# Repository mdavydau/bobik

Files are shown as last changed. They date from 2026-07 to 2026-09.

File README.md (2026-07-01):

<div align="center">

# 🤖 Tabbie  
Ever wanted a **to-do app with a Cute Face**? One that lives on your desk?

**That's Tabbie.**

[🛠️ Get started](docs/get_started.md) · [👥 Join the community](https://www.reddit.com/r/deskrobot/) · [📦 Get finished Tabbie](https://tabbie.me)

</div>

---

## 🧠 What is Tabbie?

**Tabbie is a DIY desk robot that helps you work, focus, and learn.**  
It's like a to-do app — but physical, local, and full of personality.

Tabbie lives on your desk, connects to your computer, and helps with small daily things like:
- ✅ Managing your to-do list
- ⏲️ Running Pomodoro timers
- 🔔 Setting reminders (like "drink water every 30 mins")
- 😋 Making faces, moving around, and being silly
- 🗣️ Talking to you (coming soon!)

**Think:** a mini Twitch streamer sitting on your desk, cheering you on — but also keeping you on track.

https://github.com/user-attachments/assets/2cbf9e57-a491-4764-b69d-660fd9c50714

## ✨ Made to Be Built

Tabbie is open-source and totally customizable.  
You can build it yourself with 3D-printed parts and off-the-shelf components [or just get a finished one](https://www.tabbie.me)

Powered by:
- An ESP32 microcontroller
- A local React dashboard that talks to the robot
- 3D-printed body with custom designs and colors

---

## 🚀 Get Started

Start with the step-by-step guide (WITH A **15 MINUTE VIDEO TUTORIAL**):
- 👉 See: [`docs/get_started.md`](docs/get_started.md)
- 🍎 Flash from macOS: [`docs/FLASHING_MAC.md`](docs/FLASHING_MAC.md)

That guide covers:
- Installing the Dashboard
- Flashing the ESP32 firmware
- Connecting the dashboard to your Tabbie
- First run checklist

<!-- 
**📚 Dont know anything about electronics?**  
Go here and get started → [`docs/learning/README.md`](docs/learning/README.md) — This is my mini-roadmap that I did... try learning the same _(not sure if its the best and Im kinda stupid but yea)_
-->
---

## 🗂️ Project Structure

```txt
tabbie/
├── app/                      # React control panel
│
├── firmware/                 # Code that runs on devices
│
├── hardware/                 # Physical build assets (STL files)
│
├── docs/                     # Docs (kept simple for now)
│   ├── get_started.md
│
├── CONTRIBUTING.md
└── README.md
```

---

## 🤝 Contributing

Contributions are welcome, but lets talk first!

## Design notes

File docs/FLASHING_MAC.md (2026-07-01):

# Flashing Bobik from macOS

This is the short path for rebuilding and flashing the ESP32 firmware from a
Mac.

## Fast path for Bobik

```bash
cd ~/bobik
git pull
test -f firmware/src/mqtt_config.h || cp firmware/src/mqtt_config.example.h firmware/src/mqtt_config.h
$EDITOR firmware/src/mqtt_config.h
cd firmware
pio run --target upload
```

In `firmware/src/mqtt_config.h`, keep the private broker credentials local to
your Mac. The current Bobik broker uses plain MQTT on port `1883`; do not commit
`mqtt_config.h`.

After boot, the ESP32 runs these Europe/Warsaw on-device schedules:

| Time | Face | Task |
| --- | --- | --- |
| 12:00 | `coffee` | coffee break |
| 14:30 | `status_alert` | status reminder |
| 16:00 | `sweat` | first end-of-day warning |
| 16:20 | `paused` | angrier warning |
| 16:40 | `paused` | final warning |
| 17:00 | `idle` | automatic revert from the 16:40 warning |
| 18:00-08:00 | `sleepy` | night sleepy face |
| 08:00-12:00 | `mochi_happy` | morning wake-up face |
| 00:10 | internal only | reset the stop-escalation flag for the next day |

Every real face change publishes a JSON event to MQTT topic `tabbie/notify`.
The server-side Bobik Telegram bridge subscribes to that topic and posts the
event into Bobik's Telegram channel. See
[`MQTT_BRIDGE.md`](MQTT_BRIDGE.md#4-voice-assistant-integration) for the cron
helper.

Stop the 16:00-17:00 escalation for the current day:

```bash
mosquitto_pub -h <broker-host> -p 1883 -u tabbie -P '<broker-password>' \
  -t tabbie/cmd -m '{"animation":"idle","task":"stop-escalation"}'
```

Or from the repo helper:

```bash
source .mqtt.env
tools/tabbie-pub.sh stop
```

## 1. Install tools

```bash
brew install platformio mosquitto
```

If the ESP32 does not appear as a serial port, install the CP210x driver:

```bash
brew install --cask silicon-labs-vcp-driver
```

Check the board:

```bash
pio device list
# expected: CP2102 / CP210x device, often /dev/cu.usbserial-0001
```

## 2. Create local MQTT config

```bash
cp firmware/src/mqtt_config.example.h firmware/src/mqtt_config.h
$EDITOR firmware/src/mqtt_config.h
```

Set:

```cpp
#define MQTT_HOST         "your-broker-host"
#define MQTT_PORT         1883
#define MQTT_USER         "your-user"
#define MQTT_PASS         "your-password"
```

`firmware/src/mqtt_config.h` is ignored by git. Do not commit it.

## 3. Build and upload

```bash
cd firmware
pio run
pio run --target upload --upload-port /dev/cu.usbserial-0001
```

If upload cannot connect, hold the ESP32 `BOOT` button while the upload command
is connecting.

The first clean build can take several minutes because U8g2 and the animation
headers compile from scratch. Repeat builds should be much faster.

## Preview the OLED before flashing

The app includes a local 128x64 OLED preview page. Use it to check the screen
layout and the WiFi/MQTT status overlay before uploading firmware:

```bash
cd app
PATH=/opt/homebrew/opt/node@22/bin:$PATH npm run dev -- --host 127.0.0.1
```

Open:

```text
http://127.0.0.1:8080/oled-preview.html
```

The preview can run in manual mode or poll the real device. Leave `Device URL`
as `http://tabbie.local`, or paste the direct IP address shown on the device
debug screen, for example `http://192.168.233.229`, if macOS mDNS resolution is
slow. The `PNG` button saves the current preview frame for screenshots.

When a new face header is added under `firmware/src/`, refresh the preview
assets:

```bash
python3 tools/export_oled_animations.py
```

This regenerates `app/public/animations/*.json` and `manifest.json`, and the
preview page will automatically show every exported face in the `Screen` menu.

## Mac tools for previewing and monitoring

Use these tools for different jobs:

| Tool | Best for | Install / run |
| --- | --- | --- |
| Local OLED preview | Fast face/layout checks from exported firmware assets | `cd app && PATH=/opt/homebrew/opt/node@22/bin:$PATH npm run dev -- --host 127.0.0.1` |
| Wokwi for VS Code | Full ESP32 + virtual OLED simulation without flashing hardware | Install VS Code, then install the `Wokwi Simulator` extension |
| Wokwi CLI | Terminal/CI Wokwi simulations after the VS Code setup is working | `curl -L https://wokwi.com/ci/install.sh \| sh` |
| PlatformIO monitor | Live logs from the real ESP32 over USB | `cd firmware && pio device monitor -p /dev/cu.usbserial-0001 -b 115200` |
| Arduino IDE | GUI serial monitor / serial plotter for the real ESP32 | `brew install --cask arduino-ide` |

Wokwi needs two project files in the repo root when we wire it up:
`wokwi.toml` points at the compiled firmware/ELF, and `diagram.json` describes
the ESP32 + OLED wiring. For Bobik the useful target is an ESP32 plus a 128x64
I2C SSD1306-compatible OLED. Our physical display is SH1106, but the preview
and current firmware drawing are 128x64 monochrome, so Wokwi is still useful for
screen/layout iteration before real flashing.

## 4. Configure WiFi

WiFi credentials are saved on the ESP32 in Preferences. A normal firmware upload
does not erase them.

For a new board or after reset:

1. Connect to the `Tabbie-Setup` WiFi network.
2. Open the setup page shown by the board.
3. Save the home WiFi SSID/password.
4. Let the ESP32 reboot and reconnect.

## 5. Test MQTT

Watch status:

```bash
mosquitto_sub -h your-broker-host -p 1883 -u your-user -P 'your-password' -t tabbie/status
```

Send a command:

```bash
mosquitto_pub -h your-broker-host -p 1883 -u your-user -P 'your-password' \
  -t tabbie/cmd -m '{"animation":"love","task":"mac test"}'
```

Or use the helper:

```bash
MQTT_HOST=your-broker-host MQTT_USER=your-user MQTT_PASS='your-password' \
  tools/tabbie-pub.sh love
```

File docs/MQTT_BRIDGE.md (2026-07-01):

# MQTT bridge — control Tabbie from a remote server / voice assistant

When your controller (e.g. a voice assistant) runs on a **remote server** and the
only always-on device at home is the ESP32 itself, this is the robust path: the
board **dials out** to an MQTT broker on your server and listens for commands.
No port-forwarding, no NAT holes, no always-on home box.

```
voice assistant ──publish──▶ tabbie/cmd  ┐
                                          ├─ MQTT broker (your server)
Tabbie (ESP32) ──subscribe──────────────▶┘   (board connected outbound)
Tabbie ──publish "online"──▶ tabbie/status
```

Verified working on the LAN with Mosquitto before writing this.

---

## 1. Enable the bridge in firmware

The bridge compiles **only** when `firmware/src/mqtt_config.h` exists (so the
repo still builds without it, and your broker creds stay out of git).

```bash
cd firmware/src
cp mqtt_config.example.h mqtt_config.h
$EDITOR mqtt_config.h        # set MQTT_HOST, port, MQTT_USER/MQTT_PASS
cd .. && pio run --target upload
```

`mqtt_config.h` is gitignored. Key fields:

| Define | Meaning |
|---|---|
| `MQTT_HOST` | your server's public hostname or IP |
| `MQTT_PORT` | `1883` (plain MQTT; TLS is not built in — see §5) |
| `MQTT_USER` / `MQTT_PASS` | broker credentials (comment out for anonymous) |
| `MQTT_CMD_TOPIC` | topic the board subscribes to (`tabbie/cmd`) |
| `MQTT_STATUS_TOPIC` | topic the board publishes `online` to (`tabbie/status`) |

On boot the board connects, subscribes to `MQTT_CMD_TOPIC`, retries every 5s if
the broker is down, and never blocks the display loop.

### macOS flashing notes

Install the CLI tools once:

```bash
brew install platformio mosquitto
```

Check that the ESP32 is visible:

```bash
pio device list
# or:
ls /dev/cu.*
```

Most boards appear as a CP2102/CP210x serial device such as
`/dev/cu.usbserial-0001`. If no USB serial port appears, install the Silicon
Labs driver:

```bash
brew install --cask silicon-labs-vcp-driver
```

The firmware uses `huge_app.csv` and explicit PlatformIO dependencies so clean
builds work reproducibly with the MQTT and animation assets. A first clean build
can take several minutes; repeat builds should normally finish in a few seconds.

---

## 2. Run a broker on your server (Mosquitto)

```bash
# Debian/Ubuntu
sudo apt install mosquitto mosquitto-clients

# create a user (recommended)
sudo mosquitto_passwd -c /etc/mosquitto/passwd tabbie

# /etc/mosquitto/conf.d/tabbie.conf
listener 1883 0.0.0.0
allow_anonymous false
password_file /etc/mosquitto/passwd

sudo systemctl restart mosquitto
```

Open port **1883** to the board's source (your home IP) in the server firewall.
Or run it in Docker:

```bash
docker run -d --name mosquitto -p 1883:1883 \
  -v "$PWD/mosquitto.conf:/mosquitto/config/mosquitto.conf" \
  -v "$PWD/passwd:/mosquitto/config/passwd" eclipse-mosquitto
```

---

## 3. Send commands

Commands published to `tabbie/cmd` may be **JSON** or a **bare animation name**:

```bash
# JSON
mosquitto_pub -h YOUR_SERVER -u tabbie -P secret -t tabbie/cmd \
  -m '{"animation":"paused","task":"go rest"}'

# persistent OLED DevMode diagnostics screen
mosquitto_pub -h YOUR_SERVER -u tabbie -P secret -t tabbie/cmd \
  -m '{"dev":true}'
mosquitto_pub -h YOUR_SERVER -u tabbie -P secret -t tabbie/cmd \
  -m '{"dev":false}'
mosquitto_pub -h YOUR_SERVER -u tabbie -P secret -t tabbie/cmd \
  -m '{"dev":"toggle"}'

# bare name
mosquitto_pub -h YOUR_SERVER -u tabbie -P secret -t tabbie/cmd -m love
mosquitto_pub -h YOUR_SERVER -u tabbie -P secret -t tabbie/cmd -m "dev on"
mosquitto_pub -h YOUR_SERVER -u tabbie -P secret -t tabbie/cmd -m "dev off"

# stop today's 16:00-17:00 escalation
mosquitto_pub -h YOUR_SERVER -u tabbie -P secret -t tabbie/cmd \
  -m '{"animation":"idle","task":"stop-escalation"}'
```

Or use the helper `tools/tabbie-pub.sh` (friendly words → JSON):

```bash
MQTT_HOST=YOUR_SERVER MQTT_USER=tabbie MQTT_PASS=secret \
  tools/tabbie-pub.sh angry
MQTT_HOST=YOUR_SERVER MQTT_USER=tabbie MQTT_PASS=secret \
  tools/tabbie-pub.sh dev-on
MQTT_HOST=YOUR_SERVER MQTT_USER=tabbie MQTT_PASS=secret \
  tools/tabbie-pub.sh dev-off
MQTT_HOST=YOUR_SERVER MQTT_USER=tabbie MQTT_PASS=secret \
  tools/tabbie-pub.sh debug-on
MQTT_HOST=YOUR_SERVER MQTT_USER=tabbie MQTT_PASS=secret \
  tools/tabbie-pub.sh stop
```

Animations: `idle focus break paused`(animated angry)` love pomodoro complete startup sweat sleepy coffee mochi_happy mochi_angry mochi_love upiir_big_smile status_alert`.
DevMode is the internal debug screen. It is a live feature flag toggled over
MQTT, so switching it on/off does not require reflashing. It stays on until
switched off and rotates through WiFi/MQTT, current face/task/schedule, and
system values. The helper accepts both `dev-*` and `debug-*` aliases for this
screen. Use `/api/debug` for the shorter 8-second status screen. While DevMode
is on, the firmware also writes a compact snapshot to the USB serial log every
5 seconds.

Mochi-style faces can be switched over MQTT with friendly aliases:

```bash
tools/tabbie-pub.sh mochi-happy
tools/tabbie-pub.sh mochi-angry
tools/tabbie-pub.sh mochi-love
tools/tabbie-pub.sh big-smile
tools/tabbie-pub.sh status-alert
tools/tabbie-pub.sh sleepy
```

---

## 4. Voice-assistant integration

On the server, the voice assistant should call `tools/tabbie-pub.sh`. The
script publishes to `tabbie/cmd`; Bobik receives the command over MQTT and
changes the face without reflashing.

Server setup:

```bash
cd /root/bobik
source .mqtt.env

# Smoke test: should switch the device immediately.
tools/tabbie-pub.sh status-alert "voice assistant smoke test"
```

Expected `.mqtt.env` variables:

```bash
export MQTT_HOST=localhost
export MQTT_PORT=1883
export MQTT_USER=tabbie
export MQTT_PASS='your-broker-password'
export MQTT_TOPIC=tabbie/cmd
export MQTT_NOTIFY_TOPIC=tabbie/notify
```

Intent mapping:

```
"make tabbie angry"       -> tools/tabbie-pub.sh angry
"tabbie focus mode"       -> tools/tabbie-pub.sh focus
"tabbie celebrate"        -> tools/tabbie-pub.sh complete
"tabbie mochi happy"      -> tools/tabbie-pub.sh mochi-happy
"tabbie mochi angry"      -> tools/tabbie-pub.sh mochi-angry
"tabbie mochi love"       -> tools/tabbie-pub.sh mochi-love
"tabbie big smile"        -> tools/tabbie-pub.sh big-smile
"tabbie status reminder"  -> tools/tabbie-pub.sh status-alert
"tabbie sleepy"           -> tools/tabbie-pub.sh sleepy
"tabbie dev mode on"      -> tools/tabbie-pub.sh dev-on
"tabbie dev mode off"     -> tools/tabbie-pub.sh dev-off
"bobik stop"              -> tools/tabbie-pub.sh stop
```

Watch the board come/go online:

```bash
source .mqtt.env
mosquitto_sub -h "$MQTT_HOST" -p "$MQTT_PORT" -u "$MQTT_USER" -P "$MQTT_PASS" -t tabbie/status
```

Forward face-change events to Bobik's Telegram channel by subscribing the server
bridge to `tabbie/notify`. The ESP32 publishes this topic whenever the current
face actually changes, no matter whether the change came from the on-device
schedule, HTTP dashboard, MQTT command, or an automatic return to idle.

Example event:

```json
{"event":"face-change","anim":"sleepy","animation":"sleepy","task":"sleepy time","uptime":12345,"time":"2026-07-01 19:34"}
```

Minimal server setup for Telegram forwarding:

```bash
cd /root/bobik
source .mqtt.env
source .telegram.env
tools/tabbie-notify-telegram.sh once
```

Expected `.telegram.env` variables:

```bash
export TELEGRAM_BOT_TOKEN='your-telegram-bot-token'
export TELEGRAM_CHAT_ID='your-chat-or-channel-id'
```

Create both files from the committed examples, then fill in real server values:

```bash
cp .mqtt.env.example .mqtt.env
cp .telegram.env.example .telegram.env
$EDITOR .mqtt.env .telegram.env
```

For the current Bobik flow, run the helper from cron every minute. It listens
for almost the full minute, forwards any `tabbie/notify` events, then exits so
cron can start the next window:

```cron
* * * * cd /root/bobik && . ./.mqtt.env && . ./.telegram.env && flock -n /tmp/tabbie-notify.lock tools/tabbie-notify-telegram.sh cron >> /var/log/tabbie-notify.log 2>&1
```

This creates the live loop:

```text
ESP32 schedule/face change -> tabbie/notify -> MQTT broker -> cron helper -> Telegram
Telegram/assistant "stop" -> tools/tabbie-pub.sh stop -> tabbie/cmd -> ESP32
```

Check the currently shown face from the LAN:

```bash
curl -s http://192.168.233.229/api/status
```

Direct raw MQTT payloads also work if the assistant cannot call shell scripts:

```bash
mosquitto_pub -h "$MQTT_HOST" -p "$MQTT_PORT" -u "$MQTT_USER" -P "$MQTT_PASS" \
  -t tabbie/cmd -m '{"animation":"status_alert","task":"voice assistant"}'
```

The after-hours behaviour now runs on the ESP32 itself: escalation happens at
16:00/16:20/16:40, `sleepy` holds from 18:00 until 08:00, and `mochi_happy`
wakes Bobik up from 08:00 until the noon coffee break. The legacy
`tools/tabbie_mood.sh` script is only for manual experiments.

---

## 5. Security

- The board uses **plain MQTT (1883)** — fine on a trusted network/VPN, but over
  the public internet anyone who reaches the broker can drive your Tabbie.
  **Always set a broker username/password** (§2) and restrict port 1883 by source
  IP. Avoid anonymous brokers except for LAN testing.
- TLS (port 8883) isn't compiled in to keep flash small; if you need it, add
  `WiFiClientSecure` + the broker CA and rebuild (there's now plenty of flash
  with the `huge_app` partition).

---

## 6. Local LAN test (what was used to verify this)

```bash
# on a Mac/PC on the same WiFi as Tabbie
brew install mosquitto
printf 'listener 1883 0.0.0.0\nallow_anonymous true\n' > /tmp/m.conf
mosquitto -c /tmp/m.conf -v        # note this machine's LAN IP

# set MQTT_HOST in mqtt_config.h to that LAN IP, reflash, then:
mosquitto_pub -h <lan-ip> -t tabbie/cmd -m '{"animation":"love"}'
```

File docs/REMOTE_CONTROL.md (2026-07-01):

# Controlling Tabbie remotely (incl. from a voice assistant)

Tabbie runs a small HTTP server on the ESP32. Anything that can reach the board
on the network can drive its face with a single HTTP request — no app required.
This doc covers the API, a helper CLI, how to reach the board from another
machine (e.g. a server running a voice assistant), and the security caveats.

> **About the servo / "motor":** the firmware calls `moveServoTo()` for a neck
> servo on **GPIO 13**. If no servo is attached those calls are harmless no-ops —
> the ESP32 just writes a PWM value to an unconnected pin. Faces work without any
> motor. Add a servo later and head-movement starts working with no code change.

---

## 1. HTTP API

Base URL: `http://<tabbie-host>` where `<tabbie-host>` is `tabbie.local`
(mDNS) or the board's LAN IP (e.g. `192.168.233.229`). CORS is open (`*`).

| Method | Path | Body | Purpose |
|---|---|---|---|
| `GET`  | `/api/status` | — | JSON: status, current animation, ip, ssid, rssi, uptime |
| `POST` | `/api/animation` | `{"animation":"<name>","task":"<text>","duration":<sec>}` | Set the face. `duration` only used by `focus`. |
| `POST` | `/api/servo` | (test payload) | Manually exercise the neck servo |
| `POST` | `/api/debug` | — | Show device info on screen briefly |
| `POST` | `/api/reset` | — | Clear WiFi creds and reboot into setup mode |

`GET /api/status` also includes `devMode`. Over MQTT, publish `{"dev":true}`,
`{"dev":false}`, or `{"dev":"toggle"}` to show or hide the persistent on-device
DevMode diagnostics screen. The helper supports `tools/tabbie-pub.sh dev-on`,
`dev-off`, `debug-on`, and `debug-off` aliases for the same screen.

### Expressions (`animation` values)

`idle` · `focus` · `break` · `paused` (animated **angry**) · `love` ·
`pomodoro` · `complete` · `startup` · `sweat` · `coffee` ·
`mochi_happy` · `mochi_angry` · `mochi_love` · `upiir_big_smile` ·
`status_alert`

Friendly helper aliases: `mochi-happy`, `mochi-angry`, `mochi-love`,
`big-smile`, `status-alert`.

### Examples

```bash
# status
curl -s http://tabbie.local/api/status

# angry face (the animated one), with a label
curl -s -X POST http://tabbie.local/api/animation \
  -H "Content-Type: application/json" \
  -d '{"animation":"paused","task":"after hours - go rest"}'

# focus for 25 minutes
curl -s -X POST http://tabbie.local/api/animation \
  -H "Content-Type: application/json" \
  -d '{"animation":"focus","duration":1500}'
```

---

## 2. The `tabbie-ctl` helper

`tools/tabbie-ctl.sh` wraps the API with friendly words, ideal for a voice
assistant to shell out to.

```bash
tools/tabbie-ctl.sh angry              # -> paused (animated angry)
tools/tabbie-ctl.sh focus "report"     # -> focus, labelled
tools/tabbie-ctl.sh status             # JSON status
TABBIE_HOST=192.168.233.229 tools/tabbie-ctl.sh happy
```

Friendly words: `angry happy done focus break pomodoro idle hello` (plus any raw
animation name). Set `TABBIE_HOST` to the board's hostname/IP (default
`tabbie.local`).

---

## 3. Reaching the board from another machine

The board is a normal HTTP host on your LAN. How a *server* reaches it depends on
where that server lives.

### A. Server is on the same network (simplest)
Use the board directly — nothing else needed:
```bash
TABBIE_HOST=tabbie.local tools/tabbie-ctl.sh angry
```
If `tabbie.local` doesn't resolve on the server, use the IP (find it in
`/api/status` while on the LAN, or your router's client list). Consider giving
the board a **DHCP reservation** so its IP never changes.

### B. Server is remote (different network) — recommended: Tailscale
The board sits behind your home router's NAT, so a remote server can't reach
`192.168.x.x` directly. The board can't run a VPN client itself, so put an
**always-on machine on the home LAN** (a Raspberry Pi, mini-PC, or any box) on a
[Tailscale](https://tailscale.com) tailnet, then either:

- **Subnet router** — enable subnet routes for your LAN (e.g. `192.168.233.0/24`)
  on that home node (`tailscale up --advertise-routes=192.168.233.0/24`). The
  remote server, also on the tailnet, can then hit `http://192.168.233.229`
  directly. Run `tabbie-ctl` from the server.
- **SSH hop** — simplest if you don't want subnet routing: the server runs
  `ssh homenode 'TABBIE_HOST=192.168.233.229 ~/tabbie/tools/tabbie-ctl.sh angry'`.

This keeps the board off the public internet entirely.

### C. Router port-forward (quick, **insecure**)
Forward an external port to the board's port 80. ⚠️ The board has **no
authentication** — exposing it publicly lets anyone change the face or factory-
reset WiFi. Only do this behind a reverse proxy that adds auth/TLS, or don't.

### D. MQTT bridge (most robust for remote)
Have the ESP32 **dial out** to an MQTT broker running on your server and
subscribe to a command topic. This traverses NAT with no home node and no port-
forwarding — the board initiates the connection. This is implemented with
`PubSubClient`; enable it by creating `firmware/src/mqtt_config.h`.
See [`MQTT_BRIDGE.md`](MQTT_BRIDGE.md).

---

## 4. Voice-assistant integration

Map intents to shell calls (or direct HTTP). Examples:

```
intent "make tabbie angry"   -> tabbie-ctl angry
intent "tabbie focus mode"   -> tabbie-ctl focus
intent "tabbie how are you"  -> tabbie-ctl status   (then read back the JSON)
```

If your assistant can only do HTTP, point it at
`POST http://<host>/api/animation` with the JSON body above.

---

## 5. Running without your laptop

The normal daily mood schedule now runs on the ESP32 itself, so it does not
depend on a laptop or cron. The board handles the 16:00 escalation, `sleepy`
from 18:00 to 08:00, and the morning `mochi_happy` wake-up after NTP time sync.
The legacy `tools/tabbie_mood.sh` script is only for manual experiments.

---

## 6. Security notes

- No auth + open CORS: treat the API as **LAN-only** unless fronted by a proxy
  that adds authentication.
- `/api/reset` wipes saved WiFi credentials — keep it unreachable from untrusted
  networks.
- Prefer Tailscale (§3B) over port-forwarding (§3C).

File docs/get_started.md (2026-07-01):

# Getting Started with Tabbie

A mini Twitch streamer on your desk, cheering you on, but also keeping you focused. Lets make one

---

## What You'll Need

### The Parts (~$18 USD / ~€16 EUR total)
- **ESP32** (the robot's brain)
- **1.3" OLED Screen** (the face)
- **3D Printed Parts** (the body)
- **Jumper Wires** (connecting everything)

I recommend buying the parts on **Amazon or Aliexpress**  
**Amazon** is safe choice and fast shipping, but will be more expensive  
**Aliexpress** is cheaper, but things sometimes arrive broken and shipping takes long  

**Amazon EU:**
- [ESP32 USB-C](https://amzn.to/4mDWJ6Z) (~14 EUR) 
- [OLED Screen - Pack of 3](https://amzn.to/4nxXHCO) (~18.99 EUR)
- [JumperWires -  Full pack](https://amzn.to/4mOGZ0I) (~6.40 EUR)
- [PLA Filament for 3D printing](https://amzn.to/46QfHkC) (~14 EUR)

**Amazon US**
- [ESP32 USB-C](https://amzn.to/4mGymW4) (~13.99 USD)
- [OLED Screen](https://amzn.to/4nGTbSQ) (~17.99 USD)
- [JumperWires -  Full pack](https://amzn.to/4nFxh2a) (~6.80 USD)
- [PLA Filament for 3D printing](https://amzn.to/46yAlqL) (~13.99 USD)

**Aliexpress Worldwide:**
- [ESP32 USB-C](https://s.click.aliexpress.com/e/_c3wydxSb) (~6.99 USD / 5.20 EUR a piece)
- [1.3 INCH OLED Screen white](https://s.click.aliexpress.com/e/_c30oI6Nd) (~5.35 USD / 4.50 EUR)
- [JumperWires](https://s.click.aliexpress.com/e/_c3SbwD0R) (~3.30 USD / 2.59 EUR)
- [PLA Filament for 3D printing](https://s.click.aliexpress.com/e/_c3O5ECAR) (~15.50 USD / 13.50 EUR)

*These are affiliate links - I get 3% at no extra cost to you!*

## **Don't want to deal with parts & printing?** [Just buy a finished one here](https://www.tabbie.me)

<div align="center">

### **START. How to Build Tabbie**
**The video below covers everything for both Windows and Mac users.**

</div>

Watch the video (https://youtu.be/l_Xwujika5U)

---

### STEP 1: Install & Download 

>Install:
1. **Node.js** (v18 or newer) - [Download](https://nodejs.org/) - Runs the dashboard web app
2. **Visual Studio Code** - [Download](https://code.visualstudio.com/) - Editor to view and modify code
3. **PlatformIO** (for programming the ESP32) - [Download](https://platformio.org/) - Uploads firmware to ESP32
4. **Git** - [Download Git](https://git-scm.com/)  To download via command line using `git clone`  

On macOS, the command-line setup is:

```bash
brew install platformio mosquitto
```

If the ESP32 serial port does not show up under `/dev/cu.*`, install the CP210x
USB driver:

```bash
brew install --cask silicon-labs-vcp-driver
```

>Download:

**Option A: Using Git**   

```bash
git clone https://github.com/mdavydau/bobik.git
cd bobik
```

**Option B: Download as ZIP**

- Go to https://github.com/Peeeeteer/tabbie
- Click the green “Code” button
- Select “Download ZIP”
- Extract it somewhere easy to find

*[Image here showing how to download ZIP]*

### STEP 2: Print the Body/Enclosure   

1. Use the STL files from the `/hardware` folder & print
      - `hardware/GCODE.bgcode`
      - `hardware/STL/antenna.stl`
      - `hardware/STL/antenna2.stl`
      - `hardware/STL/bottom_case.stl`
      - `hardware/STL/case.stl`
      - `hardware/STL/neck.stl`
      - `hardware/STL/panel.stl`
      - `hardware/STL/top_case.stl`

**Tip:** Turn on supports for `neck.stl` and `top_case.stl` 

### STEP 3: Install ESP32 Drivers

Your ESP32 (brains) needs special drivers to talk to your computer.

**Windows Users:**
1. Download drivers from [Silicon Labs](https://www.silabs.com/software-and-tools/usb-to-uart-bridge-vcp-drivers?tab=downloads)
2. Install them
3. Plug in your ESP32 with a USB cable
4. Open Device Manager - you should see "Silicon Labs CP210x USB to UART Bridge"

**Mac/Linux Users:**
- Usually works automatically when you plug it in
- If it doesn't work, type this in Terminal: `brew install --cask silicon-labs-vcp-driver`

---

### STEP 4: Connect the Parts

**Wiring Guide:**
1. Partly Asemble Enclosure (as per video)
2. Connect the OLED screen to ESP32:
   - SDA wire → GPIO 21 (D21)
   - SCK/SCL wire → GPIO 22 (D22)
   - VDD → 3.3V 
   - GND → GND (Ground)

Keep it partly assembled (we need to upload code and make sure everything works first)

GG. done

---

### STEP 5: Program Your ESP32

1. **Navigate to the firmware folder:**

```bash
cd firmware
```

2. **Optional: enable MQTT remote control**

If you want Bobik to connect to a remote MQTT broker, create a local config:

```bash
cp src/mqtt_config.example.h src/mqtt_config.h
$EDITOR src/mqtt_config.h
```

Fill in `MQTT_HOST`, `MQTT_PORT`, `MQTT_USER`, and `MQTT_PASS`.
`src/mqtt_config.h` is ignored by git so credentials do not get committed.
See [`MQTT_BRIDGE.md`](MQTT_BRIDGE.md) for the full MQTT setup.

3. **Upload the code to your ESP32:**

The first clean build can take a few minutes because U8g2 and animation assets
are compiled. Later builds should be much faster.

```bash
pio run --target upload
```

**Tip:** If upload fails, hold down the BOOT button on your ESP32 while uploading
and make sure that your are in still in the `firmware` directory when uploading 

4. **Configure WiFi**

The current firmware stores WiFi credentials on the ESP32 itself. On a new board
or after reset, connect your computer/phone to the `Tabbie-Setup` WiFi network
and follow the setup page to save your WiFi. If the board was already configured,
normal uploads do not erase those saved WiFi settings.

5. Finish assembling Tabbie.

Put the screen in the front -> front in the head

---

### STEP 6: Set Up the React Dashboard

Open your terminal/command and run:

```bash
# Go to the dashboard folder
cd app

# Install everything it needs
npm install

# Start it up
npm run dev
```

The dashboard will open at `http://localhost:8080` in your web browser.

---

### STEP 7: Connect Everything Together

1. **Open the dashboard** at `http://localhost:8080` in your browser
2. Follow the onboarding steps
3. **Watch the magic!** Tabbie should start showing its idle animation

**Tip:** Sometimes things just break, so disconnect tabbie for a few seconds and plug back in if wifi is not connecting properly. 

---

### Let's Use Tabbie!

**Create Tasks**
- Go to the Tasks tab
- Add things you need to do
- Start pomodors for tasks
- Tick it of when finished

Tabbie will show focus, happy,relax and bored animations a long the way to keep you focused.

**Important:**  
All your tasks/notes etc... are only saved on your computer, no one can access them.

---

## Troubleshooting

### ESP32 Won't Connect
- Double-check your WiFi name and password in the `.env` file and press "save"
- Make sure your ESP32 and computer are on the same WiFi network

### Dashboard Won't Start
- Make sure you ran `npm install` in the `dashboard` folder
- Check that you have Node.js v18 or newer (type `node --version` to check)
- Try running `npm run dev` again from the `dashboard` folder

### Can't Upload Code to ESP32
- Install the CP2102 drivers (see Step 3)
- Hold the BOOT button on ESP32 while uploading
- Check your USB cable (some cables only charge, they don't transfer data)

**Need more help?** Join the community:
- [Discord](https://discord.gg/7er2Ysjc) - [Reddit](https://www.reddit.com/r/deskrobot/) - [YouTube](https://www.youtube.com/@LloydDecember1) - [GitHub](https://github.com/Peeeeteer/tabbie) - [X](https://x.com/lloyd_december)

---

## That's It!

If this helped you, consider giving the project a star on [GitHub](https://github.com/Peeeeteer/tabbie)!

Happy building!

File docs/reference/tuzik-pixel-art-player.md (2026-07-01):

# Тузик (Tuzik) — Pixel Art Player на ESP32-P4

**Репозиторий:** [fabkury/p3a](https://github.com/fabkury/p3a) — ⭐85 — Apache 2.0
**Плата:** Waveshare ESP32-P4-WIFI6-Touch-LCD-4B — **$39.99**

## Что это

Пиксель-арт фоторамка на 4" IPS 720×720 с触摸. Показывает:
- Makapix Club (соцсеть пиксель-арта)
- Giphy (трендовые гифки)
- Музеи через IIIF (Чикаго, Rijksmuseum, V&A...)
- PICO-8 игры через WebSocket
- Свои файлы через USB/Wi-Fi

Всё open source, Apache 2.0. ⭐85 на GitHub.

## Железо

- ESP32-P4 (RISC-V dual-core + single-core) + ESP32-C6 (Wi-Fi 6/BLE)
- 32MB PSRAM + 32MB Flash
- 4" IPS 720×720, ёмкостный touch 5 точек (GT911)
- microSD (SDIO 3.0)
- Два микрофона + спикер (ES8311 + ES7210)
- MIPI-CSI для камеры

## Связь с Bobik

| | Bobik | Tuzik |
|---|---|---|
| Чип | ESP32 WROOM | ESP32-P4 + C6 |
| PSRAM | 520KB | 32MB |
| Экран | 1.3" OLED 128×64 | 4" IPS 720×720 |
| WiFi | 4 | 6 |
| Цена | ~60 zł | $39.99 |

Tuzik — это Bobik на стероидах. В 60× больше памяти,
в 30× больше пикселей. Для тяжёлого арта и анимации.

## Что можно подсмотреть в код

- Play Scheduler — алгоритм показа контента
- Triple buffering + VSYNC
- REST API для управления
- OTA обновления
- Web UI dashboard

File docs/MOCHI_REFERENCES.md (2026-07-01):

# Mochi Reference Animations

This project can use Mochi-style GIFs as local reference material when designing
Bobik faces. Do not commit downloaded Mochi GIFs or derived headers unless the
asset license is cleared.

## Sources Checked

| Source | Useful for | Notes |
| --- | --- | --- |
| <https://github.com/pham-tuan-binh/watcher-mochi> | Full reference set | `sd_content/` has 63 GIFs. The repo states the GIF animations belong to Dasai and are included for personal use. |
| <https://github.com/huykhoong/gif2cpp> | Conversion approach | Tooling reference for GIF to C/C++ arrays for monochrome OLED displays. |
| <https://github.com/tamdilip/emote-buddy> | Web playback example | Has a cached Mochi-style `smile.gif`, not a broad face library. |
| <https://github.com/upiir/esp32s3_oled_dasai_mochi> | ESP32/OLED workflow | Good example project with Rive/PNG/GIF assets and OLED conversion links. |

## Local Adaptation

Use `tools/adapt_mochi_gif.py` to create local preview assets without touching
firmware:

```bash
tools/adapt_mochi_gif.py happy --repo watcher --out-dir /tmp/bobik-mochi
```

Output files:

- `/tmp/bobik-mochi/mochi_happy01.h`
- `/tmp/bobik-mochi/mochi_happy01.json`
- `/tmp/bobik-mochi/mochi_happy01.gif`
- `/tmp/bobik-mochi/mochi_happy01_sheet.png`

The script accepts:

```bash
# watcher-mochi sd_content/<name>.gif
tools/adapt_mochi_gif.py angry --repo watcher --out-dir /tmp/bobik-mochi

# emote-buddy assets/gifs/<name>.gif
tools/adapt_mochi_gif.py smile --repo emote-buddy --out-dir /tmp/bobik-mochi

# upiir repo root GIF
tools/adapt_mochi_gif.py RIVE_big_smile_animation.gif --repo upiir --out-dir /tmp/bobik-mochi

# arbitrary local file or URL
tools/adapt_mochi_gif.py /path/to/source.gif --name local_face01 --out-dir /tmp/bobik-mochi
```

Useful tuning options:

```bash
--max-frames 24
--fps 12
--threshold 48
--padding 10
--fit auto-crop     # default; other values: contain, stretch
--invert
```

Only move a generated `.h` into `firmware/src/` after the local preview looks
good and the asset can be used in the project.

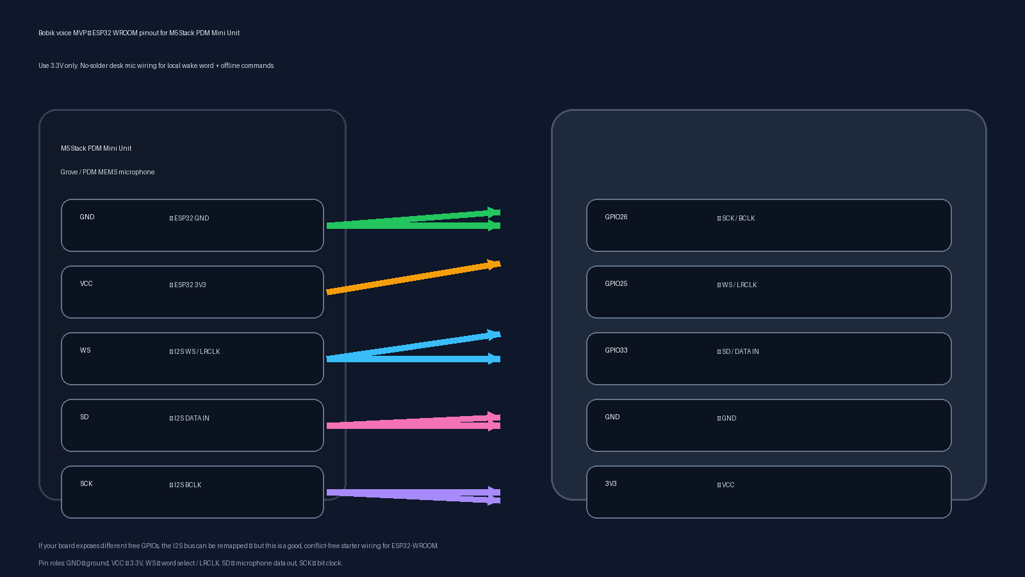
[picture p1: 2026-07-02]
docs/assets/bobik-esp32-wroom-i2s-pinout.png

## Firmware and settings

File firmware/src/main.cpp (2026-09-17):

#include <Wire.h>
#include <WiFi.h>
#include <WebServer.h>
#include <ArduinoJson.h>
#include <U8g2lib.h>
#include <Preferences.h>
#include <ESPmDNS.h>
#include <DNSServer.h>
#include <ESP32Servo.h>
#include <time.h>

// ============================================
// SERVO CONFIGURATION (SIMPLIFIED)
// ============================================
const int SERVO_PIN = 13;
Servo neckServo;

// Servo positions (degrees)
const int SERVO_LEFT = 15;
const int SERVO_CENTER = 90;
const int SERVO_RIGHT = 165;

// Servo movement
int currentServoPos = SERVO_CENTER;
int targetServoPos = SERVO_CENTER;
const int SERVO_SPEED = 8; // degrees per step (lower = slower)

// Flag: Was animation triggered via API? (forces servo active on first loop)
bool animationTriggeredViaAPI = false;

// For idle: track loops for automatic mode (every 4th loop)
int idleLoopCount = 0;
const int IDLE_SERVO_EVERY_N_LOOPS = 4;

// For paused: shake timer
unsigned long lastPausedShakeTime = 0;

// For focus: progress tracking
unsigned long focusStartTime = 0;
unsigned long focusDuration = 0;
bool focusHalfwayDone = false;

// Animation data
#include "idle01.h"
#include "focus01.h"
#include "relax01.h"
#include "love01.h"
#include "startup01.h"
#include "angry_bitmap.h"  // Static angry image (fallback)
#include "angry01.h"          // Animated angry face
#include "sweat01.h"          // Animated hot/sweating face
#include "coffee01.h"          // face: coffee
#include "mochi_happy01.h"          // face: mochi_happy
#include "mochi_angry01.h"          // face: mochi_angry
#include "mochi_love01.h"          // face: mochi_love
#include "upiir_big_smile01.h"          // face: upiir_big_smile

// Optional MQTT bridge — enabled only when firmware/src/mqtt_config.h exists.
// Lets a remote server / voice assistant control Tabbie by publishing commands
// (the board dials OUT to the broker, so it works behind home NAT).
#if defined(__has_include)
  #if __has_include("mqtt_config.h")
    #include "mqtt_config.h"
    #include <PubSubClient.h>
    #define TABBIE_MQTT 1
  #endif
#endif

// Optional Google Calendar schedule — enabled only when calendar_config.h exists.
// When on, the board polls a dedicated calendar over HTTPS and drives faces from
// it (OVERLAY: a covering calendar event wins; otherwise the built-in
// ambientWindows[]/timedEvents[] schedule governs). See calendar_config.example.h.
#if defined(__has_include)
  #if __has_include("calendar_config.h")
    #include "calendar_config.h"
    #include <WiFiClientSecure.h>
    #include <HTTPClient.h>
    #define TABBIE_CALENDAR 1
  #endif
#endif

// OLED display configuration - Using U8g2 with SH1106 driver
U8G2_SH1106_128X64_NONAME_F_HW_I2C display(U8G2_R0, /* reset=*/ U8X8_PIN_NONE);

// Web server on port 80
WebServer server(80);

// DNS server for captive portal
DNSServer dnsServer;

#ifdef TABBIE_MQTT
WiFiClient mqttWifiClient;
PubSubClient mqttClient(mqttWifiClient);
unsigned long lastMqttReconnect = 0;
void mqttLoop();
void mqttCallback(char* topic, byte* payload, unsigned int length);
void applyAnimation(const String& anim, const String& task, unsigned long durSec);
void flushPendingFaceNotification();
#endif

#ifdef TABBIE_CALENDAR
// Cached OAuth access token (refreshed from GCAL_REFRESH_TOKEN as needed).
String gcalAccessToken = "";
unsigned long gcalTokenExpiresAt = 0;     // millis() deadline; 0 = none/expired
unsigned long lastCalendarPoll = 0;
bool calendarPollPrimed = false;          // have we done the first poll yet?
// The face the calendar last drove; "" means "no covering event right now".
String calendarActiveAnim = "";
bool calendarOverrideActive = false;      // true while a calendar event owns the face
void checkCalendarSchedule();
bool gcalEnsureAccessToken();
bool gcalFetchCurrentEvent(String& animOut, String& taskOut);
bool gcalInsertEvent(const String& anim, const String& task, long startInSec, long durSec);
#endif

// WiFi credentials storage
Preferences preferences;

// Current state
String currentAnimation = "startup";
String currentTask = "";

// Token-meter: latest values pushed from the Mac via MQTT {"meter":{...}}.
// Shown by the "meter" display mode (a full-screen gauge that replaces the face).
long meterUsed = 0;      // e.g. peak context tokens of the current session
long meterLimit = 0;     // the "too much" red line (e.g. a past bloated session)
String meterLabel = "";  // short caption, e.g. "CTX"
long meterPrev = 0;      // previous active day's total, for comparison (0 = hide)
String meterPrevLabel = ""; // short tag for that day, e.g. "Fri"
long meterCl = 0;        // per-model split: claude tokens (0 = single-model day)
long meterCx = 0;        // per-model split: codex tokens
String meterSub = "";    // explicit bottom-line text; overrides the auto split/prev
long meterTot = 0;       // total tokens incl. cache (0 = limit mode; >0 = output/total mode)

// Load-driven mood face: the token level picks a face (relax→panic) and a thin
// bar is overlaid at the bottom showing how full the day is (with 1/5 ticks).
long loadUsed = 0, loadLimit = 0; // level for the bottom load-bar overlay
bool loadBarActive = false;       // draw the load bar over the current face
String loadFace = "";             // mood face currently driven by load
unsigned long statsUntil = 0;     // while now < this, show numeric stats instead of the face
int meterRate = 0;                // burn-rate position 0..100 (50 = sustainable pace)
void drawLoadBarOverlay();
void drawRateBar();
unsigned long animationStartTime = 0;
unsigned long startupTime = 0;
bool hasCompletedStartup = false;
bool isInSetupMode = false;
String wifiStatus = "disconnected";
String lastError = "";

// ============================================
// ON-DEVICE TIME & SCHEDULED ("time-related") FACES
// ============================================
// POSIX TZ for Europe/Warsaw (Poland): CET (+1) / CEST (+2) with EU DST rules.
#define TABBIE_TZ "CET-1CEST,M3.5.0,M10.5.0/3"

bool timeConfigStarted = false;      // configTzTime() has been requested
bool timeSynced = false;             // NTP returned a valid wall-clock time
unsigned long lastTimeSyncAttempt = 0;
unsigned long lastScheduleCheck = 0;

// AMBIENT FACES BY TIME-OF-DAY WINDOW
// -----------------------------------
// Each window owns a stretch of the day. The device always knows which window
// "now" falls into, so on boot (or after any restart) it shows the correct
// face for the current time — not whatever happened to fire last. A manual
// API/MQTT face selection persists until the next window boundary.
struct AmbientWindow {
  uint8_t startHour;
  uint8_t startMinute;
  const char* animation;   // must be a wired animation name (see updateDisplay)
  const char* task;
};
// MUST be sorted ascending by start time, and the first entry MUST be 00:00 so
// every moment of the day maps to exactly one window.
AmbientWindow ambientWindows[] = {
  {  0,  0, "sleepy",      "sleepy time" },   // 00:00–08:00  night
  {  8,  0, "mochi_happy", "good morning" },  // 08:00–12:00  morning
  { 12,  0, "coffee",           "coffee time" },      // 12:00–13:00  coffee break
  { 13,  0, "upiir_big_smile",  "afternoon energy" }, // 13:00–16:00  peppy afternoon
  { 16,  0, "idle",             "" },                 // 16:00–18:00  work day / anger window
  { 18,  0, "sleepy",           "sleepy time" },      // 18:00–24:00  evening wind-down
};
const int ambientWindowCount = sizeof(ambientWindows) / sizeof(ambientWindows[0]);
int currentAmbientWindow = -1;   // index last applied; -1 = none yet (fresh boot)

// ONE-SHOT TIMED EVENTS
// ---------------------
// Fire once per day at an exact hour:minute, hold for `showSec`, then revert to
// the ambient face for the current window. Unlike ambient windows these do NOT
// catch up on boot — a nag you missed is a nag you missed.
struct TimedEvent {
  uint8_t hour;
  uint8_t minute;
  const char* animation;
  const char* task;
  uint16_t showSec;        // hold time before reverting to ambient
  int lastFiredYmd;        // internal: YYYYMMDD it last fired (0 = never)
};
TimedEvent timedEvents[] = {
  // Daily status report reminder, 14:30 Europe/Warsaw.
  { 14, 30, "status_alert", "STATUS STATUS STATUS", 300, 0 },
  // Anger escalation: 16:00-17:00, levels get angrier every 20 min.
  // Cancel by sending MQTT {"animation":"idle","task":"stop-escalation"}.
  { 16,  0, "sweat",  "16:00 mozhet pora zakanchivat?", 1200, 0 },
  { 16, 20, "paused", "16:20 ya serezno, hvatit!",     1200, 0 },
  { 16, 40, "paused", "16:40 VYKLYUCHAY COMPUTER!!!",  1200, 0 },
};
const int timedEventCount = sizeof(timedEvents) / sizeof(timedEvents[0]);

// Tracks a currently-showing scheduled face so we can auto-revert it to idle,
// but only if nothing else (API/MQTT) has taken over in the meantime.
String scheduledActiveAnim = "";
unsigned long scheduledActiveStart = 0;
unsigned long scheduledRevertAt = 0;

// Anger escalation state — set to true via "stop-escalation" command
bool escalationCancelled = false;
#ifdef TABBIE_MQTT
String pendingFaceNotifyPayload = "";
bool pendingFaceNotifyDirty = false;
#endif
int escalationResetLastYmd = 0;

// WiFi connection state machine
String savedSSID = "";
String savedPassword = "";
unsigned long wifiConnectStartTime = 0;
bool wifiInitialized = false;
bool wifiConnecting = false;
bool webServerStarted = false;

const int MAX_WIFI_ATTEMPTS = 3;
int wifiAttemptCount = 0;
unsigned long wifiRetryWaitUntil = 0;

// Debug mode - shows device info on OLED when triggered
bool isDebugMode = false;
unsigned long debugModeStartTime = 0;
const unsigned long DEBUG_MODE_DURATION = 8000; // Show debug info for 8 seconds
bool devModeEnabled = false; // Persistent diagnostics screen toggled remotely
unsigned long lastDevLogAt = 0;

// Physical button for showing debug info
// Using GPIO27 - safe pin that's not a strapping pin
const int DEBUG_BUTTON_PIN = 27;
unsigned long lastButtonPress = 0;
const unsigned long BUTTON_DEBOUNCE_MS = 300; // Debounce time

// Setup mode configuration
const char* SETUP_SSID = "Tabbie-Setup";
const char* MDNS_NAME = "tabbie";

// Function declarations
void setupDisplay();
void loadWiFiCredentials();
void handleWiFiConnection();
void startSetupMode();
void startNormalMode();
void setupWebServer();
void setupMDNS();
void handleRoot();
void handleSetupPage();
void handleWiFiConfig();
void handleStatus();
void handleAnimation();
void handleWiFiSettings();
void handleCORS();
void triggerAnimation(const String& anim, const String& task, unsigned long durSec);
void publishFaceNotification(const String& anim, const String& task);
void clearScheduledFaceOverride();
void syncTimeIfNeeded();
void checkScheduledFaces();
void logDevSnapshot();
void updateDisplay();
void drawSetupMode();
void drawConnecting();
void drawConnected();
void drawError();
void drawIdleAnimation();
void drawFocusAnimation();
void drawRelaxAnimation();
void drawLoveAnimation();
void drawStartupAnimation();
void drawAngryImage();
void drawAngryAnimation();
void drawSweatAnimation();
void drawPomodoroAnimation();
void drawTaskCompleteAnimation();
void drawCoffeeAnimation();
void drawSleepyAnimation();
void drawMochi_happyAnimation();
void drawMochi_angryAnimation();
void drawMochi_loveAnimation();
void drawUpiir_big_smileAnimation();
void drawStatus_alertAnimation();
void drawMeterScreen();
void drawBmoFace(const String& mood);
void drawDebugInfo();
void drawDevInfo();
String clipForDisplay(const String& value, int maxLen);
void drawStatusMark(int x, int y, bool ok);
void drawStatusOverlay();
void flushDisplay(bool showOverlay = true);
void setDevMode(bool enabled);
void handleDebug();
void handleReset();
void handleServoTest();
void checkDebugButton();
void prepareWiFiForRetry(unsigned long delayMs = 0);
void onWiFiConnectionFailure(const String& reason);

// Servo functions
void setupServo();
void moveServoTo(int position);
void updateServoMovement();

void setup() {
  Serial.begin(115200);
  Serial.println("🤖 Tabbie Assistant Starting...");
  
  // Record startup time
  startupTime = millis();
  
  // Setup debug button (GPIO0 = BOOT button on most ESP32 boards)
  pinMode(DEBUG_BUTTON_PIN, INPUT_PULLUP);
  
  // CRITICAL: Clean WiFi state from any previous boot/mode
  // This prevents issues when switching between AP and STA modes
  WiFi.persistent(false);  // Don't save WiFi config to flash
  WiFi.disconnect(true);   // Disconnect and clear saved credentials
  WiFi.mode(WIFI_OFF);     // Turn off WiFi completely
  delay(200);              // Give hardware time to reset
  wifiAttemptCount = 0;
  wifiRetryWaitUntil = 0;
  
  // Initialize components
  setupDisplay();
  setupServo();
  
  // Initialize preferences
  preferences.begin("tabbie", false);
  
  // Load WiFi credentials (don't connect yet - animations first!)
  loadWiFiCredentials();

#ifdef TABBIE_MQTT
  // Configure the MQTT client (connection happens later, once WiFi is up)
  mqttClient.setServer(MQTT_HOST, MQTT_PORT);
  mqttClient.setCallback(mqttCallback);
  mqttClient.setBufferSize(512);
  Serial.print("📡 MQTT bridge enabled - broker ");
  Serial.print(MQTT_HOST); Serial.print(":"); Serial.println(MQTT_PORT);
#endif

  // DON'T setup web server here - it will be started in startNormalMode() or startSetupMode()
  // after WiFi is properly initialized
  
  Serial.println("✅ Tabbie initialized - animations will play while WiFi connects");
}

void setupDisplay() {
  Wire.begin(21, 22);
  
  display.begin();
  display.clearBuffer();
  // Don't show "Starting..." text - just clear the display
  // Startup animation will begin immediately in loop()
  flushDisplay(false);
  
  Serial.println("✅ OLED Display initialized (U8g2 SH1106)");
}

void setupServo() {
  ESP32PWM::allocateTimer(0);
  neckServo.setPeriodHertz(50);
  neckServo.attach(SERVO_PIN, 500, 2400);
  neckServo.write(SERVO_CENTER);
  currentServoPos = SERVO_CENTER;
  targetServoPos = SERVO_CENTER;
  Serial.println("✅ Servo initialized on GPIO " + String(SERVO_PIN));
}

// Move servo to position (sets target, updateServoMovement does the actual moving)
void moveServoTo(int position) {
  targetServoPos = constrain(position, SERVO_LEFT, SERVO_RIGHT);
  Serial.print("🎯 Servo → ");
  Serial.print(targetServoPos);
  Serial.println("°");
}
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
void loop() {
  // Check if debug button is pressed
  checkDebugButton();
  
  // Handle DNS server in setup mode
  if (isInSetupMode) {
    dnsServer.processNextRequest();
  }
  
  // Handle WiFi connection (non-blocking, runs in background)
  handleWiFiConnection();

#ifdef TABBIE_MQTT
  // Service the MQTT bridge (non-blocking; only acts once WiFi is up)
  mqttLoop();
#endif

  // Handle web server requests
  server.handleClient();

  // Keep the clock synced and fire any time-of-day scheduled faces (on-device)
  syncTimeIfNeeded();
#ifdef TABBIE_CALENDAR
  // Calendar overlay: when an event covers "now" it owns the face; otherwise the
  // built-in schedule below takes over. Runs first so it can claim/release.
  checkCalendarSchedule();
#endif
  checkScheduledFaces();
  // Load-face: after the 10s stats window on a zone change, return to the face.
  if (statsUntil != 0 && millis() >= statsUntil) {
    statsUntil = 0;
    if (loadFace.length()) {
      loadBarActive = true;
      applyAnimation(loadFace, meterLabel, 0);
    }
  }
  logDevSnapshot();

  // Update display animation (always runs, never blocked!)
  updateDisplay();
  
  // Update servo position (smooth movement towards target)
  updateServoMovement();
  
  delay(5);
}

void handleCORS() {
  server.sendHeader("Access-Control-Allow-Origin", "*");
  server.sendHeader("Access-Control-Allow-Methods", "GET, POST, OPTIONS");
  server.sendHeader("Access-Control-Allow-Headers", "Content-Type");
  server.send(200, "text/plain", "");
}

void handleRoot() {
  server.sendHeader("Access-Control-Allow-Origin", "*");
  String html = "<!DOCTYPE html><html><head><title>Tabbie Assistant</title>";
  html += "<meta name='viewport' content='width=device-width,initial-scale=1'>";
  html += "<style>body{font-family:Arial,sans-serif;max-width:900px;margin:28px auto;padding:16px;background:#f6f7f9;color:#17202a;}";
  html += ".status,.panel{background:white;padding:16px;border-radius:10px;margin:14px 0;box-shadow:0 1px 8px rgba(0,0,0,.08);}";
  html += ".grid{display:grid;grid-template-columns:repeat(auto-fit,minmax(135px,1fr));gap:10px;}";
  html += ".button{background:#18212f;color:white;padding:12px 10px;border:none;border-radius:8px;cursor:pointer;font-size:14px;text-align:left;}";
  html += ".button:hover{background:#334155;}.button.active{background:#0f766e;}.button small{display:block;opacity:.72;margin-top:3px;font-size:11px;}";
  html += ".settings{background:#007bff;text-align:center;}.danger{background:#dc3545;text-align:center;}code{font-size:13px;}</style></head><body>";
  html += "<h1>Tabbie Assistant</h1>";
  html += "<div class='status'><h3>Status: Connected!</h3>";
  html += "<p>Current Animation: <strong><span id='current-animation'>Loading...</span></strong></p>";
  html += "<p>Task: <span id='current-task'>-</span></p>";
  html += "<p>MQTT: <span id='mqtt-status'>-</span> · Time: <span id='local-time'>-</span></p>";
  html += "<p>WiFi: " + WiFi.SSID() + "</p>";
  html += "<p>IP: " + WiFi.localIP().toString() + "</p></div>";
  html += "<div class='panel'><h3>Faces</h3><div class='grid' id='faces'>";
  html += "<button class='button' data-face='idle' onclick=\"sendAnimation('idle')\">Idle<small>idle</small></button>";
  html += "<button class='button' data-face='focus' onclick=\"sendAnimation('focus','Focus Session')\">Focus<small>focus</small></button>";
  html += "<button class='button' data-face='break' onclick=\"sendAnimation('break','Break Time')\">Break / Relax<small>break</small></button>";
  html += "<button class='button' data-face='paused' onclick=\"sendAnimation('paused','Paused')\">Angry / Paused<small>paused</small></button>";
  html += "<button class='button' data-face='love' onclick=\"sendAnimation('love','Love')\">Love<small>love</small></button>";
  html += "<button class='button' data-face='pomodoro' onclick=\"sendAnimation('pomodoro','Focus Session')\">Pomodoro<small>pomodoro</small></button>";
  html += "<button class='button' data-face='complete' onclick=\"sendAnimation('complete','Task Done!')\">Complete<small>complete</small></button>";
  html += "<button class='button' data-face='startup' onclick=\"sendAnimation('startup','Hello')\">Startup<small>startup</small></button>";
  html += "<button class='button' data-face='sweat' onclick=\"sendAnimation('sweat','Hot')\">Sweat<small>sweat</small></button>";
  html += "<button class='button' data-face='coffee' onclick=\"sendAnimation('coffee','Coffee Time')\">Coffee<small>coffee</small></button>";
  html += "<button class='button' data-face='sleepy' onclick=\"sendAnimation('sleepy','Sleepy Time')\">Sleepy<small>sleepy</small></button>";
  html += "<button class='button' data-face='mochi_happy' onclick=\"sendAnimation('mochi_happy','Mochi Happy')\">Mochi Happy<small>mochi_happy</small></button>";
  html += "<button class='button' data-face='mochi_angry' onclick=\"sendAnimation('mochi_angry','Mochi Angry')\">Mochi Angry<small>mochi_angry</small></button>";
  html += "<button class='button' data-face='mochi_love' onclick=\"sendAnimation('mochi_love','Mochi Love')\">Mochi Love<small>mochi_love</small></button>";
  html += "<button class='button' data-face='upiir_big_smile' onclick=\"sendAnimation('upiir_big_smile','Big Smile')\">Big Smile<small>upiir_big_smile</small></button>";
  html += "<button class='button' data-face='status_alert' onclick=\"sendAnimation('status_alert','Status Reminder')\">Status Alert<small>status_alert</small></button>";
  html += "</div></div>";
  html += "<div class='panel'><h3>Settings</h3>";
  html += "<button class='button settings' onclick=\"window.location='/wifi'\">WiFi Settings</button>";
  html += "<button class='button danger' onclick=\"resetWiFi()\">Reset WiFi</button></div>";
  html += "<script>";
  html += "async function resetWiFi(){if(confirm('This will clear WiFi settings and restart Tabbie. Continue?')){try{await fetch('/api/reset',{method:'POST'});alert('Tabbie is restarting in setup mode...');}catch(e){alert('Tabbie is restarting...');}}}";
  html += "async function sendAnimation(type,task=''){";
  html += "try{const response=await fetch('/api/animation',{method:'POST',headers:{'Content-Type':'application/json'},body:JSON.stringify({animation:type,task:task})});";
  html += "if(response.ok){await updateStatus();}}catch(e){console.error('Failed to send animation:',e);}}";
  html += "async function updateStatus(){try{const response=await fetch('/api/status');const data=await response.json();";
  html += "document.getElementById('current-animation').textContent=data.animation||'-';";
  html += "document.getElementById('current-task').textContent=data.task||'-';";
  html += "document.getElementById('mqtt-status').textContent=data.mqttEnabled?(data.mqttConnected?'connected':'disconnected'):'off';";
  html += "document.getElementById('local-time').textContent=data.localTime||'-';";
  html += "document.querySelectorAll('[data-face]').forEach(b=>b.classList.toggle('active',b.dataset.face===data.animation));";
  html += "}catch(e){console.error('Failed to get status:',e);}}";
  html += "setInterval(updateStatus,2000);updateStatus();";
  html += "</script></body></html>";
  
  server.send(200, "text/html", html);
}
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

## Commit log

2025-12-03 testing servo movmenet that matches animations
2026-06-30 🎉 Tabbie firmware + dashboard + управляющие скрипты
    [antenna.stl, antenna2.stl, bottom_case.stl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]
2026-07-01 Add animated angry face + remote-control tooling and docs
    Firmware:
    - angry01.h: 12-frame animated angry face (generated via tools/make_face.py)
    - main.cpp: play the animated face for the "paused" state via new
    drawAngryAnimation() (replaces the static drawAngryImage in dispatch),
    keeping the 30s head-shake behavior
    Tooling (tools/):
    - tabbie-ctl.sh: friendly HTTP control CLI for scripts / voice assistants
    - make_face.py: GIF/video/PNG-sequence -> Tabbie .h face converter
    - gen_angry.py: procedural angry-face frame generator
    - demo_expressions.sh: cycle all expressions with a delay
    Docs:
    - docs/REMOTE_CONTROL.md: HTTP API reference, tabbie-ctl usage, options for
    reaching the board fr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
    [main.cpp]
2026-07-01 Add MQTT bridge for remote control behind NAT
    The ESP32 dials OUT to an MQTT broker and subscribes to a command topic, so a
    remote server / voice assistant can drive Tabbie without port-forwarding or an
    always-on home box. Verified end-to-end on the LAN with Mosquitto.
    - main.cpp: optional MQTT client (PubSubClient), enabled only when
    src/mqtt_config.h exists (via __has_include). Non-blocking connect/reconnect
    in loop(); subscribes to MQTT_CMD_TOPIC; accepts JSON or a bare animation
    name; publishes "online" to MQTT_STATUS_TOPIC. Shared applyAnimation() mirrors
    the HTTP handler.
    - platformio.ini: add knolleary/PubSubClient; switch to huge_app.csv partition
    (flash was at 96% — now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
    [main.cpp]
2026-07-01 Add custom huge_app partition table for MQTT build
    - huge_app.csv: 3MB app partition so animation frames + MQTT fit
    - .gitignore: add .mqtt.env and .mqtt-creds.txt (credentials)
    [huge_app.csv]
2026-07-01 Add OLED device status preview
2026-07-01 Add all faces to device web dashboard
2026-07-01 Fix manual face selection persistence
    [main.cpp]
2026-07-01 📺 p3a reference — Pixel Art Player на ESP32-P4
2026-07-01 🏷 Тузик — rename p3a to Tuzik
2026-07-01 Add on-device anger escalation: 16:00-17:00, 3 levels, MQTT stop
2026-07-01 Fix escalation stop schedule reset
    [main.cpp]
2026-07-01 Support Telegram forum topic thread IDs in notify bridge
2026-07-02 Add Bobik ESP32 WROOM mic pinout schematic
2026-07-02 Add Bobik ESP32 WROOM mic pinout PNG
2026-07-02 Split animation frame data into separate translation units
    Each xxx01.h defined ~thousands of lines of const PROGMEM frame bytes and
    was #included into main.cpp, making it one ~3MB translation unit. Any edit
    to main.cpp recompiled all 12 animations' bitmaps — a one-line change took
    >9 minutes to rebuild.
    Move the frame arrays into xxx01.cpp (compiled once, cached by scons) and
    leave the headers declaring only `extern const unsigned char* const
    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
2026-07-02 Add time-of-day face schedule with Google Calendar overlay
    On-device schedule now models the day as ambient windows (night/morning/
    coffee/afternoon/evening) plus one-shot timed events (status nag, anger
    escalation). The device always resolves the correct face for "now", so it
    shows the right mood on boot instead of whatever fired last. Afternoon
    13:00-16:00 gets the peppy upiir_big_smile face.
    Layered on top: an optional Google Calendar overlay (enabled when
    calendar_config.h exists). The board polls a dedicated calendar over HTTPS;
    an event covering "now" drives the face (title -> animation, description ->
    task), otherwise the built-in schedule governs — so faces still work offline.
    too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
    [main.cpp]
2026-07-06 Add token-meter: OLED gauge of daily agent token usage
    New "meter" display mode driven over MQTT ({"meter":{used,limit,label,prev,
    prevlab,cl,cx}}): a full-screen gauge that replaces the face with a big number
    (value in thousands), % of a "too much" limit, and a progress bar that blinks
    when over the red line. Bottom line shows the previous active day for
    comparison, or — when two models were used — the claude/codex split, with a
    notch on the bar marking the claude→codex boundary.
    tools/tabbie-tokenmeter.sh polls agentsview for the current metric and publishes
    to tabbie/cmd on a configurable interval (METRIC=day → today's output tokens
    across all agents via `activity report`; METRIC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
    [main.cpp]
2026-07-06 token-meter: week view, per-model split, decile ticks, layout polish
    Meter display:
    - Percentage now shows the "/540k" heavy-day reference beneath it (how much of
    a Friday-scale day is spent); OUTPUT is the headline in a slightly larger font.
    - Progress bar gets 9 decile ticks (short XOR notches on the top/bottom rails)
    so the fill level is readable at a glance, plus a notch marking the
    claude->codex boundary when two models are active.
    - New bottom-line sources: explicit `sub` text (WEEK shows last week), the
    per-model `cl`/`cx` split, or an `of N total` line from `tot` — first present
    wins. `prev`/`prevlab` show the previous active day when nothing else applies.
    Publisher (tab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
    [main.cpp]
2026-07-06 token-meter: load-driven mood face (relax->panic) with minimal gauge
    The day's load now drives Bobik's face across 5 zones (output vs the Friday-scale
    limit): break(relax) → mochi_happy → focus → sweat → paused(panic). The publisher
    maps the level to a face (zoneface) and sends it in the meter payload as `face`.
    - When a meter push carries `face`, show that mood face with a minimal bottom
    gauge overlaid via flushDisplay: a thin fill line plus 1/5..4/5 zone notches.
    - On a zone change (face differs) show the numeric stats screen for 10s, then
    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
2026-07-06 token-meter: animated procedural BMO faces wired to the load ladder
    Procedural BMO-style faces drawn entirely from primitives (dots, parabolic
    mouth curve, brows/lids) — no bitmaps, ~25fps, with idle life: gentle breathing
    bob, smooth ellipse blink, occasional sideways glance, and a panic shake with a
    nervous mouth. Five moods: bmo_bliss, bmo_happy, bmo_neutral, bmo_worried,
    bmo_panic. Trigger any via {"animation":"bmo_<mood>"}.
    The load ladder (zoneface) now emits these bmo_ faces instead of the bitmap
    ones, so Bobik's animated mood tracks the day's token load with the thin bottom
    gauge under it. Swapping the palette needed no firmware change — the meter face
    field just carries the ani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
    [main.cpp]
2026-07-06 token-meter: burn-rate arrow gauge, thin indicators, load %, model %
    Second axis — burn rate (how fast, not just how much):
    - Publisher computes a rate position 0..100 from output tokens over the last
    RATE_WINDOW_MIN (default 10), against RATE_MID tok/min at the midpoint. The
    scale is an instantaneous pace (~2500 tok/min), not the daily average, so
    ordinary work sits mid-gauge instead of pegging at 100.
    - Firmware: a thin left-edge vertical track with 1/4, 1/2, 3/4 marks and a
    left-pointing arrow at the current rate. Tremble is driven ONLY by rate
    (above 3/4) — a high-total day sits calm once you slow down.
    Readability:
    - Bottom load gauge is now a thin full-width track with 1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
    [main.cpp]
2026-09-17 chore: save current work
